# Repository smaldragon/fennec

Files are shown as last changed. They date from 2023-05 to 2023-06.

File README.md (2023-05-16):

# fennec
An Homebrew computer using the 65c02 CPU.

All assembly code is built using my custom assembler built for personal hobby use, [CapyAsm](https://github.com/smaldragon/CapyASM), these two projects are closely linked and build off eachother, *with both* currently being in a early alpha state subject to bugs and regular breaking changes.

Documentation for the machine is located on its wiki at https://fennec6502.miraheze.org/

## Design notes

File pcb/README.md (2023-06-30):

# GENERAL WARNING

These are various kicad projects developed over the course of this project, before taking a look at these it is extremely important that you understand the following:

* These projects are largely untested
* These projects were designed by a very clueless self-taught hobbyist
* I do not recommend using any of these for any purpose without scrutiny

## The projects

### 40key BreadKeys

A 40% mechanical keyboard matrix (8x5) designed to be hooked up to a breadboard via DuPont jumpers.

### MinFox 

A minimal expandable 65c02 sbc built for debugging peripherals, it contains ROM, RAM and 6 "slot select" lines (same terminology as the Fennec) that allow easily adding expansion chips without extra hardress decoding logic.

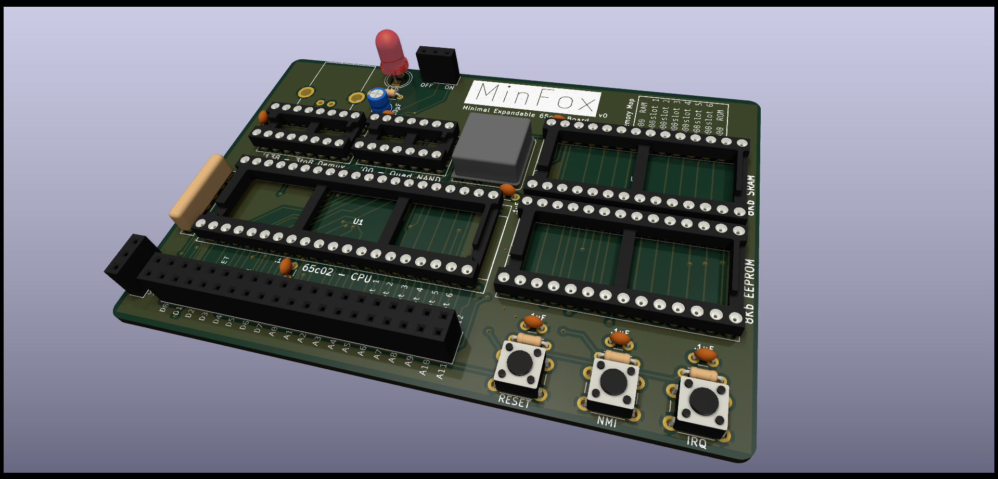
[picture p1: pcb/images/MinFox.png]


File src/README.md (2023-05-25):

# Fennec Source

## Executables

This folder contains the assembly source and data files for the current prototype testing program, these are separated into 2 parts that must be assembled seperately, as followed using CapyASM:

* `capyasm -i boot.asm` - This is the boot rom, placed within an assumed 8Kb EEPROM, it initializes an sd card and loads a run.65x file from it. Placed at address **$E000**
* `capyasm -i run.asm` - This is the executable program that is stored on the sd card, the resulting file should be named "RUN.65X" and stored in the root of the card, which should be formated to FAT32. Placed at address **$0800** to **$7FFF** (using bank 0).

## Font

The system font is the file `font.png`, which must be converted into a binary `font.bin` by running the python 3 script `font.py`. It is a 256 character font using 4x8 tiles.

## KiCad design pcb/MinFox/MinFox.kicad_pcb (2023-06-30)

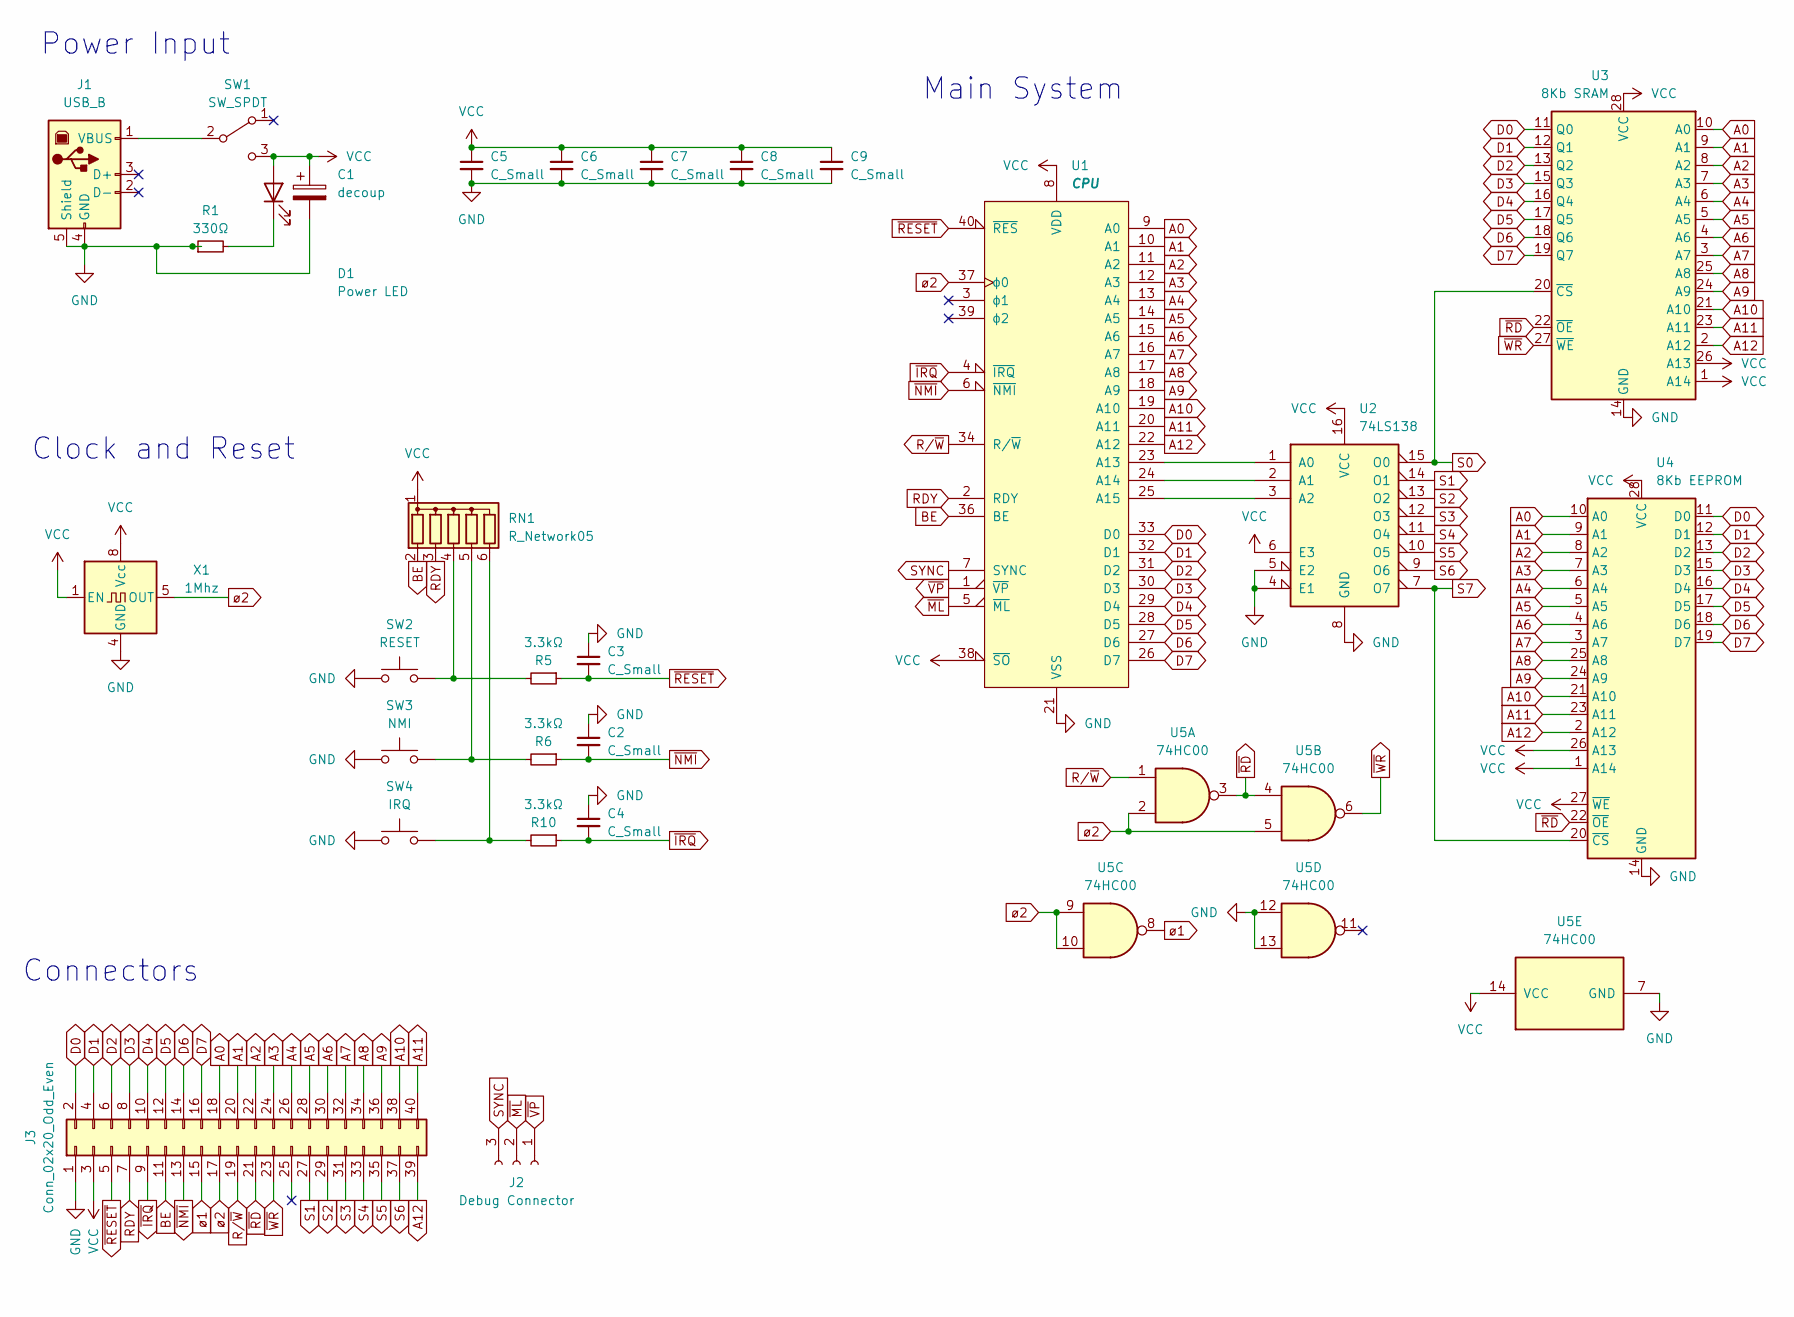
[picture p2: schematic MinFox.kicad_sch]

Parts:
C1: decoup; CP_Radial_D4.0mm_P1.50mm
C2, C3, C4, C5, C6, C7, C8, C9: C_Small; C_Disc_D3.0mm_W1.6mm_P2.50mm
D1: Power LED; LED_D5.0mm
J1: USB_B; USB_B_OST_USB-B1HSxx_Horizontal
J2: Debug Connector; PinSocket_1x03_P2.54mm_Vertical
J3: Conn_02x20_Odd_Even; PinSocket_2x20_P2.54mm_Vertical
R1: 330Ω; R_Axial_DIN0204_L3.6mm_D1.6mm_P5.08mm_Horizontal
R5, R6, R10: 3.3kΩ; R_Axial_DIN0204_L3.6mm_D1.6mm_P5.08mm_Horizontal
RN1: R_Network05; R_Array_SIP6
SW1: SW_SPDT; PinSocket_1x03_P2.54mm_Vertical
SW2: RESET; SW_PUSH_6mm
SW3: NMI; SW_PUSH_6mm
SW4: IRQ; SW_PUSH_6mm
U1: CPU; DIP-40_W15.24mm_Socket
U2: 74LS138; DIP-16_W7.62mm_Socket
U3: 8Kb SRAM; DIP-28_W15.24mm_Socket
U4: 8Kb EEPROM; DIP-28_W15.24mm_Socket
U5: 74HC00; DIP-14_W7.62mm_Socket
X1: 1Mhz; Oscillator_DIP-8

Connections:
A0: J3.18, U1.9 (A0), U3.10 (A0), U4.10 (A0)
A1: J3.20, U1.10 (A1), U3.9 (A1), U4.9 (A1)
A2: J3.22, U1.11 (A2), U3.8 (A2), U4.8 (A2)
A3: J3.24, U1.12 (A3), U3.7 (A3), U4.7 (A3)
A4: J3.26, U1.13 (A4), U3.6 (A4), U4.6 (A4)
A5: J3.28, U1.14 (A5), U3.5 (A5), U4.5 (A5)
A6: J3.30, U1.15 (A6), U3.4 (A6), U4.4 (A6)
A7: J3.32, U1.16 (A7), U3.3 (A7), U4.3 (A7)
A8: J3.34, U1.17 (A8), U3.25 (A8), U4.25 (A8)
A9: J3.36, U1.18 (A9), U3.24 (A9), U4.24 (A9)
A10: J3.38, U1.19 (A10), U3.21 (A10), U4.21 (A10)
A11: J3.40, U1.20 (A11), U3.23 (A11), U4.23 (A11)
A12: J3.39, U1.22 (A12), U3.2 (A12), U4.2 (A12)
BE: J3.11, RN1.2 (R1), U1.36 (BE)
D0: J3.2, U1.33 (D0), U3.11 (Q0), U4.11 (D0)
D1: J3.4, U1.32 (D1), U3.12 (Q1), U4.12 (D1)
D2: J3.6, U1.31 (D2), U3.13 (Q2), U4.13 (D2)
D3: J3.8, U1.30 (D3), U3.15 (Q3), U4.15 (D3)
D4: J3.10, U1.29 (D4), U3.16 (Q4), U4.16 (D4)
D5: J3.12, U1.28 (D5), U3.17 (Q5), U4.17 (D5)
D6: J3.14, U1.27 (D6), U3.18 (Q6), U4.18 (D6)
D7: J3.16, U1.26 (D7), U3.19 (Q7), U4.19 (D7)
GND: C1.2, C2.1, C3.1, C4.1, C5.2, C6.2, C7.2, C8.2, C9.2, J1.4 (GND), J1.5 (Shield), J3.1, R1.1, SW2.1, SW3.1, SW4.1, U1.21 (VSS), U2.4 (E1), U2.5 (E2), U2.8 (GND), U3.14 (GND), U4.14 (GND), U5.7 (GND), U5.12, U5.13, X1.4 (GND)
unnamed: D1.1 (K), R1.2
unnamed: J1.1 (VBUS), SW1.2 (B)
unnamed: R5.2, RN1.4 (R3), SW2.2
unnamed: R6.2, RN1.5 (R4), SW3.2
unnamed: R10.2, RN1.6 (R5), SW4.2
unnamed: U1.23 (A13), U2.1 (A0)
unnamed: U1.24 (A14), U2.2 (A1)
unnamed: U1.25 (A15), U2.3 (A2)
RDY: J3.7, RN1.3 (R2), U1.2 (RDY)
R/~W: J3.19, U1.34 (R/~W), U5.1
S0: U2.15 (O0), U3.20 (~CS)
S1: J3.27, U2.14 (O1)
S2: J3.29, U2.13 (O2)
S3: J3.31, U2.12 (O3)
S4: J3.33, U2.11 (O4)
S5: J3.35, U2.10 (O5)
S6: J3.37, U2.9 (O6)
S7: U2.7 (O7), U4.20 (~CS)
SYNC: J2.3, U1.7 (SYNC)
VCC: C1.1, C5.1, C6.1, C7.1, C8.1, C9.1, D1.2 (A), J3.3, RN1.1 (common), SW1.3 (C), U1.8 (VDD), U1.38 (~SO), U2.6 (E3), U2.16 (VCC), U3.1 (A14), U3.26 (A13), U3.28 (VCC), U4.1 (A14), U4.26 (A13), U4.27 (~WE), U4.28 (VCC), U5.14 (VCC), X1.1 (EN), X1.8 (Vcc)
~IRQ: C4.2, J3.9, R10.1, U1.4 (~IRQ)
~ML: J2.2, U1.5 (~ML)
~NMI: C2.2, J3.13, R6.1, U1.6 (~NMI)
~RD: J3.21, U3.22 (~OE), U4.22 (~OE), U5.3, U5.4
~RESET: C3.2, J3.5, R5.1, U1.40 (~RES)
~VP: J2.1, U1.1 (~VP)
~WR: J3.23, U3.27 (~WE), U5.6
ø1: J3.15, U5.8
ø2: J3.17, U1.37 (ϕ0), U5.2, U5.5, U5.9, U5.10, X1.5 (OUT)

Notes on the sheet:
Clock and Reset
Main System
Power Input
Connectors

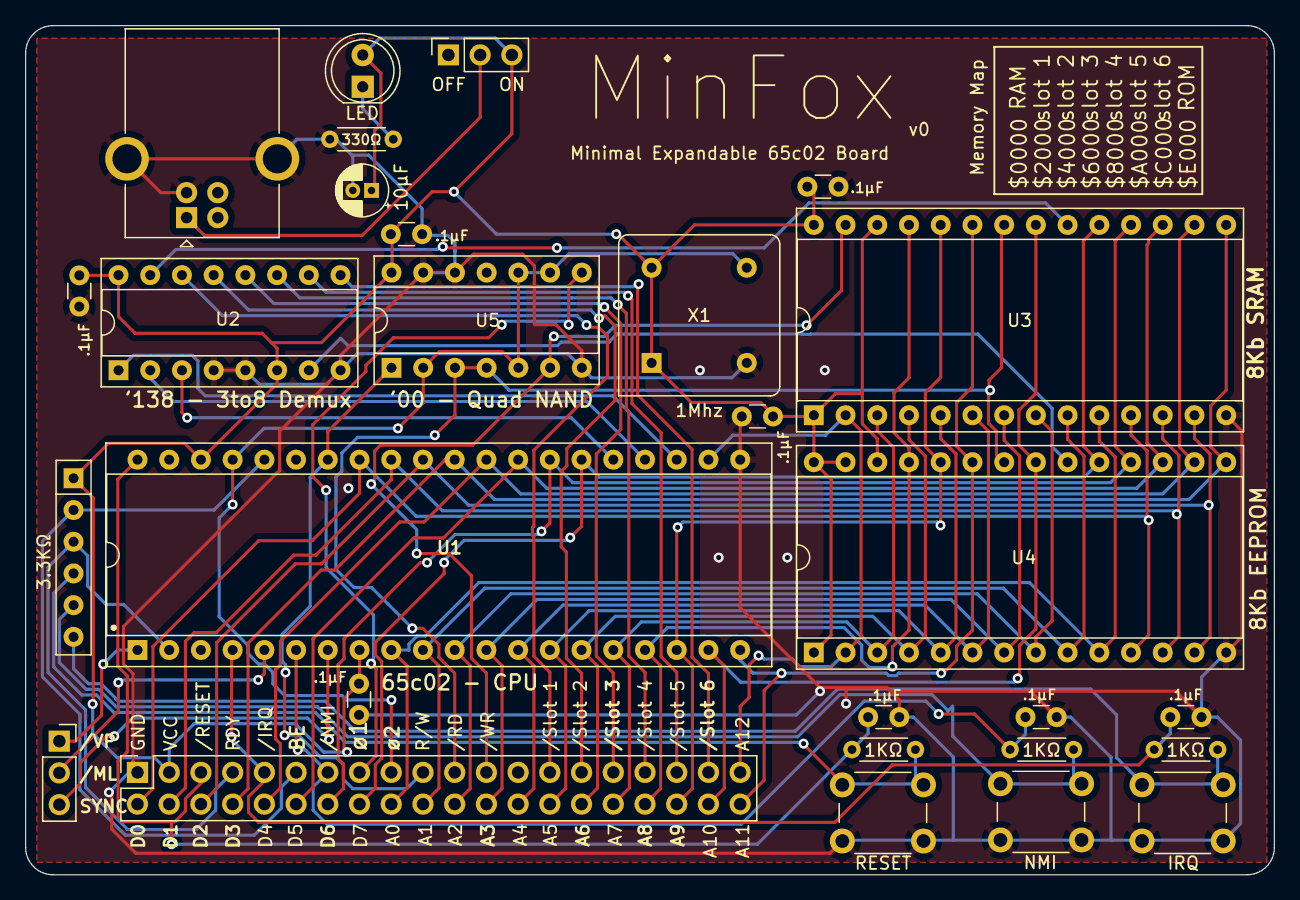
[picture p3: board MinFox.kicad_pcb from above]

Board: 2 copper layers, 100.0 x 68.0 mm, 28 parts (0 on the bottom side), 52 nets.

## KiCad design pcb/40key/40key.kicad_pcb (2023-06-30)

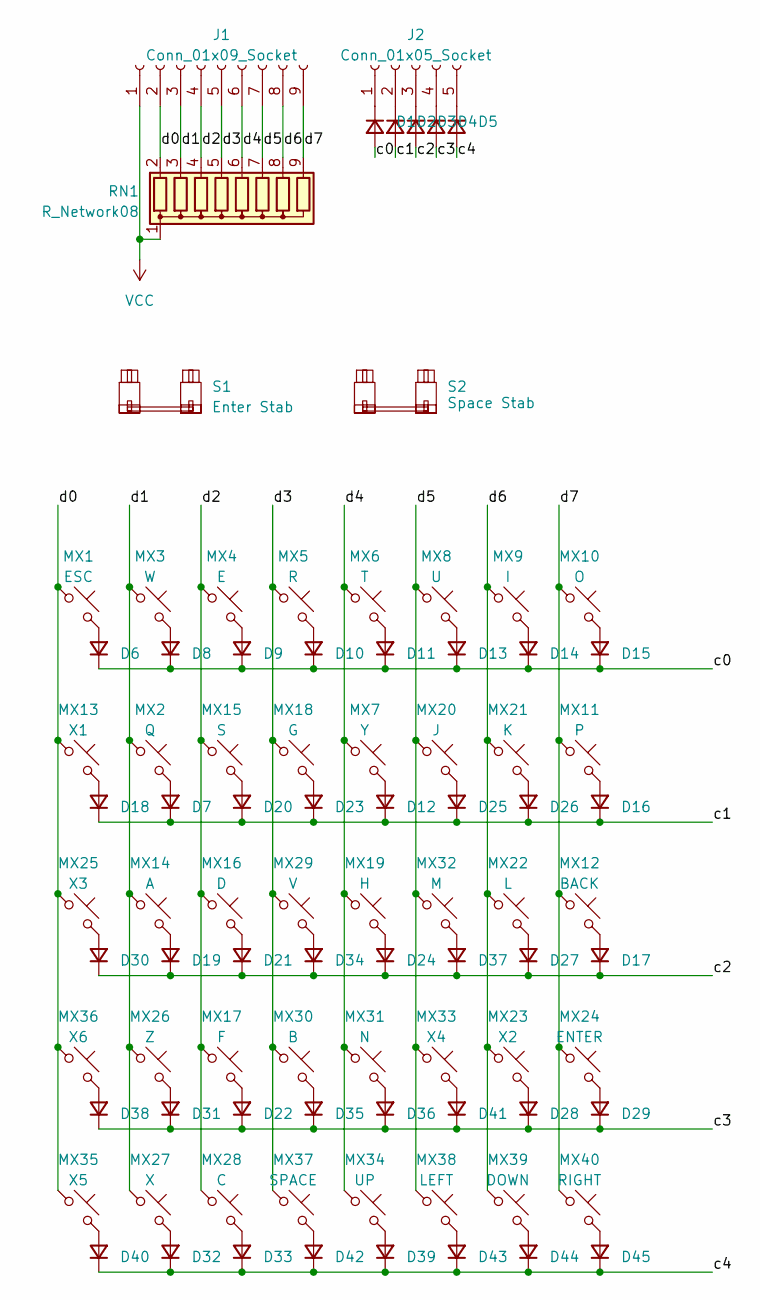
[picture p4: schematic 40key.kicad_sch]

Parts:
D1, D2, D3, D4, D5, D6, D7, D8, D9, D10, D11, D12, D13, D14, D15, D16, D17, D18, D19, D20, D21, D22, D23, D24, D25, D26, D27, D28, D29, D30, D31, D32, D33, D34, D35, D36, D37, D38, D39, D40, D41, D42, D43, D44, D45: D_Small; D_DO-34_SOD68_P7.62mm_Horizontal
J1: Conn_01x09_Socket; PinHeader_1x09_P2.54mm_Vertical
J2: Conn_01x05_Socket; PinSocket_1x05_P2.54mm_Vertical
MX1: ESC; SW_MX_1u
MX2: Q; SW_MX_1u
MX3: W; SW_MX_1u
MX4: E; SW_MX_1u
MX5: R; SW_MX_1u
MX6: T; SW_MX_1u
MX7: Y; SW_MX_1u
MX8: U; SW_MX_1u
MX9: I; SW_MX_1u
MX10: O; SW_MX_1u
MX11: P; SW_MX_1u
MX12: BACK; SW_MX_1.25u
MX13: X1; SW_MX_1.25u
MX14: A; SW_MX_1u
MX15: S; SW_MX_1u
MX16: D; SW_MX_1u
MX17: F; SW_MX_1u
MX18: G; SW_MX_1u
MX19: H; SW_MX_1u
MX20: J; SW_MX_1u
MX21: K; SW_MX_1u
MX22: L; SW_MX_1u
MX23: X2; SW_MX_1u
MX24: ENTER; SW_MX_1u
MX25: X3; SW_MX_1.75u
MX26: Z; SW_MX_1u
MX27: X; SW_MX_1u
MX28: C; SW_MX_1u
MX29: V; SW_MX_1u
MX30: B; SW_MX_1u
MX31: N; SW_MX_1u
MX32: M; SW_MX_1u
MX33: X4; SW_MX_1.5u
MX34: UP; SW_MX_1u
MX35: X5; SW_MX_1.25u
MX36: X6; SW_MX_1.75u
MX37: SPACE; SW_MX_1u
MX38: LEFT; SW_MX_1u
MX39: DOWN; SW_MX_1u
MX40: RIGHT; SW_MX_1u
RN1: R_Network08; R_Array_SIP9
S1: Enter Stab; STAB_MX_2u
S2: Space Stab; STAB_MX_6.25u

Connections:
/c0: D1.2 (A), D6.1 (K), D8.1 (K), D9.1 (K), D10.1 (K), D11.1 (K), D13.1 (K), D14.1 (K), D15.1 (K)
/c1: D2.2 (A), D7.1 (K), D12.1 (K), D16.1 (K), D18.1 (K), D20.1 (K), D23.1 (K), D25.1 (K), D26.1 (K)
/c2: D3.2 (A), D17.1 (K), D19.1 (K), D21.1 (K), D24.1 (K), D27.1 (K), D30.1 (K), D34.1 (K), D37.1 (K)
/c3: D4.2 (A), D22.1 (K), D28.1 (K), D29.1 (K), D31.1 (K), D35.1 (K), D36.1 (K), D38.1 (K), D41.1 (K)
/c4: D5.2 (A), D32.1 (K), D33.1 (K), D39.1 (K), D40.1 (K), D42.1 (K), D43.1 (K), D44.1 (K), D45.1 (K)
/d0: J1.2, MX1.1, MX13.1, MX25.1, MX35.1, MX36.1, RN1.2 (R1)
/d1: J1.3, MX2.1, MX3.1, MX14.1, MX26.1, MX27.1, RN1.3 (R2)
/d2: J1.4, MX4.1, MX15.1, MX16.1, MX17.1, MX28.1, RN1.4 (R3)
/d3: J1.5, MX5.1, MX18.1, MX29.1, MX30.1, MX37.1, RN1.5 (R4)
/d4: J1.6, MX6.1, MX7.1, MX19.1, MX31.1, MX34.1, RN1.6 (R5)
/d5: J1.7, MX8.1, MX20.1, MX32.1, MX33.1, MX38.1, RN1.7 (R6)
/d6: J1.8, MX9.1, MX21.1, MX22.1, MX23.1, MX39.1, RN1.8 (R7)
/d7: J1.9, MX10.1, MX11.1, MX12.1, MX24.1, MX40.1, RN1.9 (R8)
unnamed: D1.1 (K), J2.1
unnamed: D2.1 (K), J2.2
unnamed: D3.1 (K), J2.3
unnamed: D4.1 (K), J2.4
unnamed: D5.1 (K), J2.5
unnamed: D6.2 (A), MX1.2
unnamed: D7.2 (A), MX2.2
unnamed: D8.2 (A), MX3.2
unnamed: D9.2 (A), MX4.2
unnamed: D10.2 (A), MX5.2
unnamed: D11.2 (A), MX6.2
unnamed: D12.2 (A), MX7.2
unnamed: D13.2 (A), MX8.2
unnamed: D14.2 (A), MX9.2
unnamed: D15.2 (A), MX10.2
unnamed: D16.2 (A), MX11.2
unnamed: D17.2 (A), MX12.2
unnamed: D18.2 (A), MX13.2
unnamed: D19.2 (A), MX14.2
unnamed: D20.2 (A), MX15.2
unnamed: D21.2 (A), MX16.2
unnamed: D22.2 (A), MX17.2
unnamed: D23.2 (A), MX18.2
unnamed: D24.2 (A), MX19.2
unnamed: D25.2 (A), MX20.2
unnamed: D26.2 (A), MX21.2
unnamed: D27.2 (A), MX22.2
unnamed: D28.2 (A), MX23.2
unnamed: D29.2 (A), MX24.2
unnamed: D30.2 (A), MX25.2
unnamed: D31.2 (A), MX26.2
unnamed: D32.2 (A), MX27.2
unnamed: D33.2 (A), MX28.2
unnamed: D34.2 (A), MX29.2
unnamed: D35.2 (A), MX30.2
unnamed: D36.2 (A), MX31.2
unnamed: D37.2 (A), MX32.2
unnamed: D38.2 (A), MX36.2
unnamed: D39.2 (A), MX34.2
unnamed: D40.2 (A), MX35.2
unnamed: D41.2 (A), MX33.2
unnamed: D42.2 (A), MX37.2
unnamed: D43.2 (A), MX38.2
unnamed: D44.2 (A), MX39.2
unnamed: D45.2 (A), MX40.2
VCC: J1.1, RN1.1 (common)

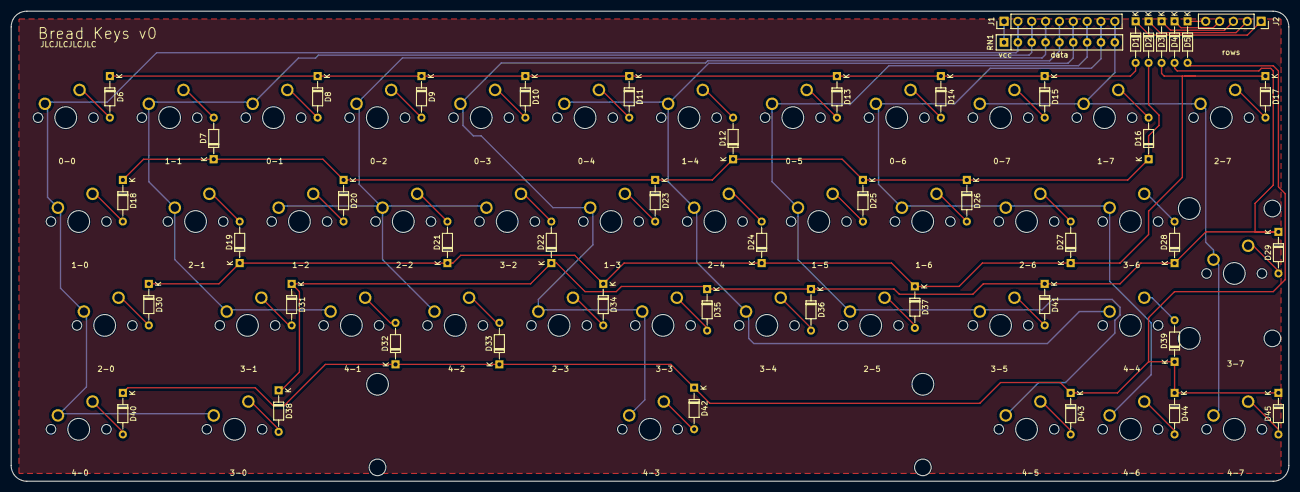
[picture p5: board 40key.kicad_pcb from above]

Board: 2 copper layers, 234.3 x 86.2 mm, 90 parts (0 on the bottom side), 59 nets.

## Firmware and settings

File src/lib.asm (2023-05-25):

.cpu 65c02

.macro spi_lcd
    lda {0}; sta [M_LCD]; nop; nop; nop; lda [M_LCD]
.endmacro

.var lcd_on     %1010_1111
.var lcd_off    %1010_1110
.var lcd_scroll %01_000000
.var lcd_page   %1011_0000
.var lcd_cmsb   %0001_0000
.var lcd_clsb   %0000_0000
.var lcd_mx     %1010_0000
.var lcd_my     %1100_0000
.var lcd_inv    %1010_0110
.var lcd_all    %1010_0100

.var lcd_power  %0010_1000
.var lcd_regu   %0010_0000
.var lcd_ev     %1000_0001
.var lcd_boost  %1111_1000
.var lcd_bias   %1010_0010

.var lcd_inc    %1110_0000
.var lcd_end    %1110_1110
.var lcd_reset  %1110_0010
.var lcd_nop    %1110_0011

.var M_DUMMY    $8000
.var M_A0       $8010
.var M_LCD      $8020
.var M_BEEP     $8070
.var ROM        $E000

_contrast
    # Takes a 8-bit value and uses it to adjust contrast settings
    tax
    
    lda lcd_ev; sta [M_LCD]; nop; nop; nop; lda [M_LCD]    # EV
    txa; and %000_1111; sta [M_LCD]; nop; nop; nop; lda [M_LCD] # EV
    txa; lsr A; lsr A; lsr A; lsr A; and %0000_0111; clc; adc lcd_regu; sta [M_LCD]; nop; nop; nop; lda [M_LCD] # RES

    lda lcd_boost; sta [M_LCD]; nop; nop; nop; lda [M_LCD]    # BOOST
    txa; rol; rol; and 1; sta [M_LCD]; nop; nop; nop; lda [M_LCD]    # BOOST

    rts

_beep
    ldy $20
    _waitlong
    # beep off
    lda [M_BEEP]
    ldx $80
    __wait1
    dec X; bne (wait1)

    # beep on
    lda $FF
    sta [M_BEEP]
    ldx $80
    __wait2
    dec X; bne (wait2)
    dec Y; bne (waitlong)
    
    rts

_charout
    psh X
    tax
    lda [M_A0]
    
    lda [font + X]
    sta [M_LCD]; nop; lda [font + 256 + X]; bit [M_LCD]
    sta [M_LCD]; nop; lda [font + 512 + X]; bit [M_LCD]
    sta [M_LCD]; nop; lda [font + 768 + X]; bit [M_LCD]
    sta [M_LCD]; nop; pul X; bit [M_LCD]
    sta [M_A0]; nop; nop
    rts
_stringout
    pha
    phx
    phy
    # zp 0-1 contains the address of the string to read, 
    # prints characters to lcd until a zero is hit
    # a string can be max 255 chars
    lda [M_A0]
    ldy 0
    __loop
    lda [<$00>+Y]   # cur char to X
    tax
    beq (end)       # we break if the current char is zero
    
    #1  2  3  4  5  6  7  8  9  A
    #nop...nop...nop...bit.x..y.rd
    #nop...lda.x..y.rd.bit.x..y.rd
    lda [font + X]
    sta [M_LCD]; nop; lda [font + 256 + X]; bit [M_LCD]
    sta [M_LCD]; nop; lda [font + 512 + X]; bit [M_LCD]
    sta [M_LCD]; nop; lda [font + 768 + X]; bit [M_LCD]
    sta [M_LCD]; nop; nop; inc Y; bit [M_LCD]
    
    tya             # get string offset back from Y
    
    bra (loop)
    
    __end
    sta [M_A0]
    pla
    plx
    ply
    rts
    
_setpage
    sta [M_A0]; nop; nop; nop

    clc; adc lcd_page
    sta [M_LCD]; nop; nop; nop; lda [M_LCD]
    
    rts
    
_setline
    phx
    sta [M_A0]; nop; nop; nop

    tax
    and $F0
    lsr A; lsr A; lsr A; lsr A; ora lcd_cmsb
    sta [M_LCD]; txa; and $0F; nop; bit [M_LCD]
    sta [M_LCD]; nop; nop; nop; bit [M_LCD]
    
    plx
    rts
    
_setcursor
    # Cursor location is stored in A and is a value from 0 to 255
    sta <$04>; lsr A; lsr A; lsr A; lsr A; lsr A
    jsr [setpage]
    
    lda <$04>; and %0001_1111; asl A; asl A; clc; adc 4
    jsr [setline]
    
    lda [M_A0]
    rts

_clrscreen
    # Set lcd address (col MSB, col LSB, col wow)
    lda 4; jsr [setline]
    lda 0; jsr [setpage]
    
    lda [M_A0]
    ldx 0
    __clear_loop
    stz [M_LCD]; nop; nop; nop; ldy [M_LCD]
    stz [M_LCD]; nop; nop; nop; ldy [M_LCD]
    stz [M_LCD]; nop; nop; nop; ldy [M_LCD]
    stz [M_LCD]; nop; nop; nop; ldy [M_LCD]
    
    inc X; txa; and %0001_1111
    
    bne (skip)
        sta [M_A0]
        txa
        lsr A; lsr A; lsr A; lsr A; lsr A; ora %1011_0000; sta [M_LCD]; nop; nop; nop; lda [M_LCD]
        lda lcd_cmsb;    sta [M_LCD]; nop; nop; nop; lda [M_LCD] # COLUMN MSB
        lda %0000_0100; sta [M_LCD]; nop; nop; nop; lda [M_LCD] # COLUMN LSB
        lda [M_A0]
    __skip
    
    txa; bne (clear_loop)
    
    sta [M_A0]
    rts

_font
.bin "font.bin"

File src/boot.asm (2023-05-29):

.cpu 65c02

.var M_DUMMY    $8000
.var M_A0       $8010
.var M_LCD      $8020
.var M_SD       $8030
.var M_RTC      $8040
.var M_BEEP     $8070
.var M_BANK     $8001
.var ROM        $E000

.var zp_fat32_variables $10

.var f32_vbr                  zp_fat32_variables + $00
.var f32_tables               zp_fat32_variables + $04
.var f32_data                 zp_fat32_variables + $08
.var f32_cur                  zp_fat32_variables + $0C
.var f32_clustersize          zp_fat32_variables + $10  # 1 byte
.var f32_sectorcount          zp_fat32_variables + $11


.macro spi_lcd
    lda {0}; sta [M_LCD]; nop; nop; nop; lda [M_LCD]
.endmacro


.macro spi_sd
    lda {0}; sta [M_LCD]; nop; nop; nop; lda [M_LCD]
.endmacro

.org [ROM]
    # setup spi ports (all ports are set low on reset)
    #   Dummy        A0           LCD              SD Card              n/a           Beeper
    lda [$8000];                  lda [$8020];                          lda [$8050]; lda [$8060];
    
    jsr [beep]
    
    # SD CARD INIT
    
    lda 'F'; sta [$0403]; stz [$0404];stz [$0405]
    # cmd0 reset
    lda sdcmd0.lo; sta <$00>
    lda sdcmd0.hi; sta <$01>
    ldx $FF
    stx [M_DUMMY]; nop; nop; nop; nop
    stx [M_SD]; nop; nop; nop; nop
    
    jsr [sdcmd]; sta [$0400]
    bit [M_SD]

    # cmd8 if_cond
    lda sdcmd8.lo; sta <$00>
    lda sdcmd8.hi; sta <$01>
    jsr [sdcmd]; sta [$0401]
    lda $FF
    sta [M_DUMMY]; nop; nop; nop; nop
    sta [M_DUMMY]; nop; nop; nop; nop
    sta [M_DUMMY]; nop; nop; nop; nop
    sta [M_DUMMY]; nop; nop; nop; nop
    bit [M_SD]
    
    ldx $FF
    _sdinit
        ldy $FF
        __delay
            nop; nop; nop; nop; nop; nop; nop; nop; nop; nop; nop; nop;
            dec Y
        bne (delay)
        # This is a two byte command, cmd55 followed by acmd41
        dec X
        bne (next)
        jmp [initfail]
        __next
        lda sdcmd55.lo; sta <$00>
        lda sdcmd55.hi; sta <$01>
        jsr [sdcmd]; sta [$0402]
        bit [M_SD]
        
        lda sdcmd41.lo; sta <$00>
        lda sdcmd41.hi; sta <$01>
        jsr [sdcmd]; sta [$0403]
        bit [M_SD]; clc; adc 0
    bne (sdinit)
    
    # Open SD CARD Sector 0 (MASTER BOOT RECORD MBR) and find a FAT32 PART
    stz <$00>; stz <$01>; stz <$02>; stz <$03>; stz <$04>; lda $05; sta <$05>; jsr [sdsector]
    
    lda [$06FE]; sta [$0404]
    lda [$06FF]; sta [$0405]
    stz [$0406]
    
    ldx 0
    lda [$06BE+$04+X]
    cmp 12; beq (foundpart)
    ldx 16
    lda [$06BE+$04+X]
    cmp 12; beq (foundpart)
    ldx 32
    lda [$06BE+$04+X]
    cmp 12; beq (foundpart)
    ldx 48
    lda [$06BE+$04+X]
    cmp 12; beq (foundpart)
    
    jmp [initfail]
    
    _foundpart
    # JUMP to and Save FAT32 VBR VOLUME BOOT RECORD
    lda [$06BE+$08+X]; sta <$00>
    lda [$06BE+$09+X]; sta <$01>
    lda [$06BE+$0A+X]; sta <$02>
    lda [$06BE+$0B+X]; sta <$03>
    stz <$04>; lda $05; sta <$05>
    jsr [sdsector]
    
    lda [$06FE]; sta [$0406]
    lda [$06FF]; sta [$0407]
    stz [$0408]
    
    lda <$00>; sta <f32_vbr+0>
    lda <$01>; sta <f32_vbr+1>
    lda <$02>; sta <f32_vbr+2>
    lda <$03>; sta <f32_vbr+3>
    
    # Calculate start of FAT tables
    clc
    lda [$050E]; adc <$00>; sta <f32_tables+0>
    lda [$050F]; adc <$01>; sta <f32_tables+1>
    lda 0      ; adc <$02>; sta <f32_tables+2>
    lda 0      ; adc <$03>; sta <f32_tables+3>
    
    lda [$050D]; sta <f32_clustersize>
    
    # ______ Calculate Start of DATA
    # Add the size of the table area + 2 to start of tables to get the start of the DATA
    clc; rol [$0524]; rol [$0525]; rol [$0526]; rol [$0527]
    clc
    lda <f32_tables+0>; adc [$0524]; sta <f32_data+0>
    lda <f32_tables+1>; adc [$0525]; sta <f32_data+1>
    lda <f32_tables+2>; adc [$0526]; sta <f32_data+2>
    lda <f32_tables+3>; adc [$0527]; sta <f32_data+3>
    
    lda <f32_tables+0>; sta <$00>
    lda <f32_tables+1>; sta <$01>
    lda <f32_tables+2>; sta <$02>
    lda <f32_tables+3>; sta <$03>
    stz <$04>; lda $05; sta <$05>
    jsr [sdsector]
    
    lda <f32_data+0>; sta <$00>
    lda <f32_data+1>; sta <$01>
    lda <f32_data+2>; sta <$02>
    lda <f32_data+3>; sta <$03>
    stz <$04>; lda $05; sta <$05>
    jsr [sdsector]
  
    _initfail
    lda [M_SD]
    stz [M_DUMMY]; nop; nop; nop
    
    # LCD INIT
    
    lda %1010_1111; sta [$8020]; nop; nop; nop; lda [$8020] # Display ON
    lda %0010_1111; sta [$8020]; nop; nop; nop; lda [$8020] # Enable Power
    
    # Set mirroring
    lda %1010_0001; sta [$8020]; nop; nop; nop; lda [$8020] # MX
    lda %1100_1000; sta [$8020]; nop; nop; nop; lda [$8020] # MY
    jsr [beep]
    
    lda 235; jsr [contrast]
    jsr [clrscreen]
    
    # Loading the string data into all 8 banks
    ldx 0
_bank_write
        stx [M_BANK]
        stx [$4300]
        inc X
    bne (bank_write)
    
    lda $FF
    ldx $FE
    ldy $01
_bank_calc
        stx [M_BANK]
        cmp [$4300]; bcc (end)
        tya; sed; clc; adc 1; cld; tay
        txa
        dec X
    bne (bank_calc)
    __end
    lda $E0; jsr [setcursor]
    tya
    lsr A; lsr A; lsr A; lsr A; clc; adc $30; jsr [charout]
    tya
    and $0F; clc; adc $30; jsr [charout]
    lda bankstr.lo; sta <$00>
    lda bankstr.hi; sta <$01>
    jsr [stringout] 
    
    # Print out sd response
    lda $ED; jsr [setcursor]
    lda $00; sta <$00>
    lda $04; sta <$01>
    jsr [stringout]
    lda $04; sta <$00>
    lda $04; sta <$01>
    jsr [stringout]
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
